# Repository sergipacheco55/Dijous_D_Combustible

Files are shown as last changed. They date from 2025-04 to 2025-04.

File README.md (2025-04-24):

View this project on [CADLAB.io](https://cadlab.io/project/29049). 

# EL COMBUSTIBLE

## Autors
- Raúl Carod (RaulCarod)
- Sergi Pacheco (sergipacheco55)

## Versió - v1.0 ## Curs - Assignatura de Disseny de PCBs amb KiCad - [Curs 2024-2025]

## Objectiu Descripció breu de l'objectiu del projecte.
L'objectiu del projecte és crear una pcb capaç de controlar el mecanisme de tancament de dipòsit del combustible d'un cotxe, controli el sensor de pressió de pneumàtics i el sensor digital de nivell de combustible i el funcionament de la bomba de combustible.
## Requisits i especificacions
- Una etapa regulador de tensió per alimentar tots el components de la placa.
- Tenir un microcontrolador encarregat del control de la nostra placa.
- Tenir una connexió BUS CAN, I2C.
- Una comuniació USART per connectar el microcontrolador a aparells extern ja ve sigui un ordinador.
- Tenir entrades com un boto per a que s'interección amb la placa.

## Diagrama de blocs
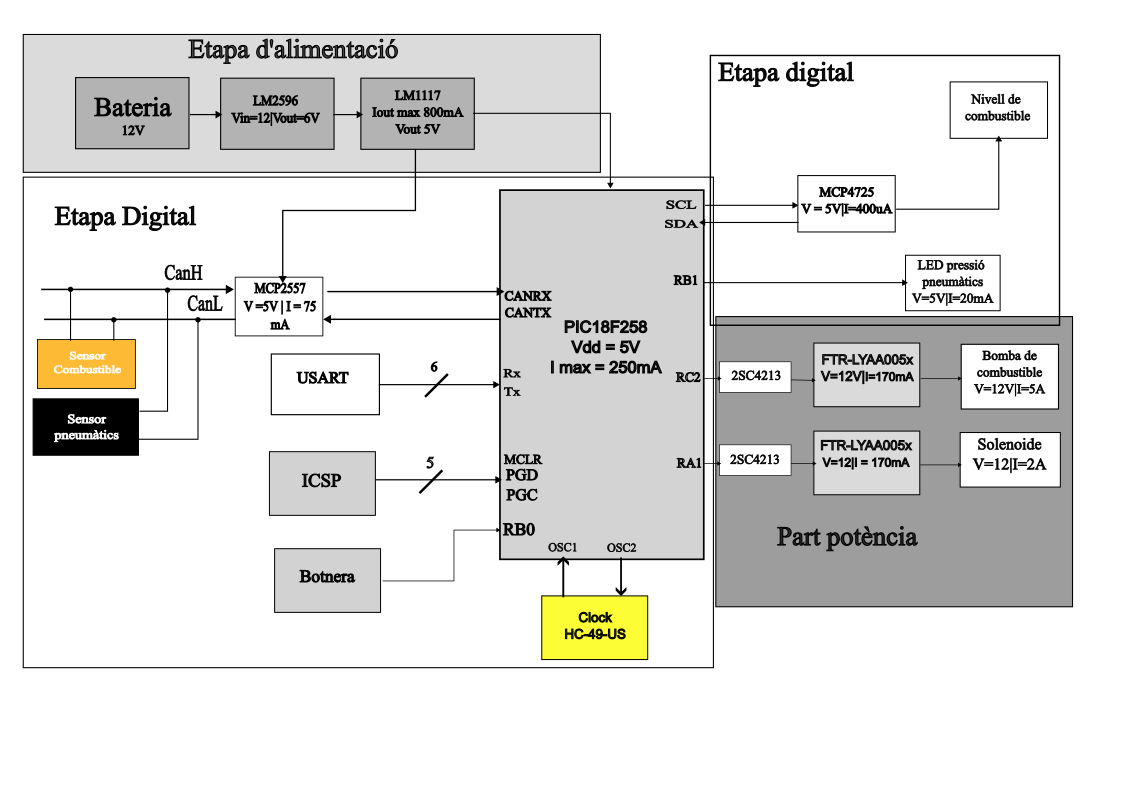
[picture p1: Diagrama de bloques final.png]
Diagrama de bloques


## Taula de components
| Descripció | Manufacturer Number | Package  | Datasheet | Proveïdor | Unitats |
|---|---|---|---|---|---|
| Regulador de tensió | LM1117 | SOT-223 | [Enllaç](https://www.ti.com/lit/ds/symlink/lm1117.pdf) | Mouser | 1 |
| Regulador de commutació | LM2596 | TO-220 / TO-263 | [Enllaç](https://www.ti.com/lit/ds/symlink/lm2596.pdf) |Mouser | 1 |
| Transceptor CAN | MCP2557 | SOIC-8  | [Enllaç](https://www.digikey.es/es/products/detail/microchip-technology/MCP2557FD-H-SN/6009299?productid=6009299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) | DigiKey | 1 |
| Microcontrolador | PIC18F258 | SOIC 28 | [Enllaç](https://ww1.microchip.com/downloads/en/devicedoc/39564c.pdf) | DigiKey / Mouser | 1 |
| Cristall de quars | abls-4.000mhz-b2-t | HC-49-SD | [Enllaç](https://www.mouser.es/ProductDetail/ABRACON/ABLS-4000MHZ-B2-T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) | Mouser | 1 |
| Convertidor DAC | MCP4725 | SOT-23-6 | [Enllaç](https://ww1.microchip.com/downloads/en/devicedoc/22039d.pdf) | DigiKey / Mouser | 1 |
| Transistor de control | 2SC4213 | SMD:SOT-323 | [Enllaç](https://toshiba.semicon-storage.com/info/docget.jsp?did=19305&prodName=2SC4213) | Mouser | 2 |
| Relé | Fujitsu_FTR-LYAA005Y | SPST-Vertical | [Enllaç](https://www.fujitsu.com/sg/imagesgig5/ftr-ly.pdf) | Mouse | 2 |
| Díode protector | PMEG6030EP | Diode_SMD:D_SOD-128 | [Enllaç](https://www.vishay.com/docs/88516/1n5400.pdf) | Mouser | 4 |
| Díode Zener | 1N5822 | DO-201AD | [Enllaç](http://www.vishay.com/docs/88526/1n5820.pdf) | Farnell España | 1 |
| LED Blau | 150080BS75000 | 0805_2012 | [Enllaç](https://www.we-online.com/components/products/datasheet/150080BS75000.pdf)| Digikey | 2 |
| LED Verd | 150080GS75000 | 0805_2012 | [Enllaç](https://www.we-online.com/components/products/datasheet/150080GS75000.pdf)| Digikey | 1 |
| LED Blau | 150080SS75000 | 0805_2012 | [Enllaç](https://www.we-online.com/components/products/datasheet/150080SS75000.pdf)| Digikey | 1 |
| Connector Bateria | 691137710002 | TERM BLK 2POS SIDE ENTRY 5MM PCB | [Enllaç](https://www.we-online.com/components/products/datasheet/691137710002.pdf) | Digikey | 1 |
| Connector 01x02 | 61300211121 | PinHeader_1x02_P2.54mm_Vertical | [Enllaç](https://www.we-online.com/components/products/datasheet/61300211121.pdf) |Digikey | 4 |
| Connector ISCP | 61200621621 | PinHeader_2x03_P2.54mm_Vertical | [Enllaç](https://www.we-online.com/components/products/datasheet/61200621621.pdf) | Digikey | 1 |
| Connector Usart | 61300611121 | PinHeader_1x06_P2.54mm_Vertical | [Enllaç](https://www.we-online.com/components/products/datasheet/61300611121.pdf) | Digikey | 1 |
| Connector 01x03 | G800LR305018EU | FanPinHeader_1x03_P2.54mm_Vertical | [Enllaç](https://cdn.amphenol-cs.com/media/wysiwyg/files/drawing/g800lrxxxxxxeu_1.pdf) |Mouser | 1 |
| Jumper | 60900213421 | JUMPER W/TEST PNT 1X2PINS 2.54MM | [Enllaç](https://www.we-online.com/components/products/datasheet/60900213421.pdf) | Digikey | 1 |
| Pulsador reset | SKRKAEE020 | SW_Push_SPST_NO_Alps_SKRK | [Enllaç](https://www.mouser.es/datasheet/2/15/SKRK-1370789.pdf) | Mouser | 1 |
| Connector DB9 | DE09-PT-1 | DSUB-9_Male_Vertical_P2.77x2.84mm | [Enllaç](https://app.adam-tech.com/products/download/data_sheet/198661/dxxx-pt-1-data-sheet.pdf) | Digikey | 1 |
| Díode de protecció de connexió | PMEG040V050EPD | CFP15_SOT-1289 | [Enllaç](https://assets.nexperia.com/documents/data-sheet/PMEG040V050EPD.pdf) | Digikey | 1 |

## Funcionalitats
- El mecanisme de tancament i obertura del dipòsit de combustible
- Un sensor digital del nivell de combustible
- El mecanisme que controli la bomba de combustible
- Un sensor que ens avisi quan la pressió dels pneumàtics sigui baixa

## Historial de canvis
| Data | Autor | Branch | Descripció |
|---|---|---|---|
| 2025-03-20 | Sergi Pacheco | `main` | Creació del projecte |
| 2025-03-24 | Raúl Carod| `main` | Diagrama de blocs |
| 2025-03-24 | Sergi Pacheco| `main`| Llista de materials|
| 2025-03-24 | Raúl Carod | `main`| Esquemàtic entrades |
| 2025-03-25 | Raúl Carod | `main`| Esquemàtic microcontrolador|
| 2025-03-26 | Sergi Pacheco| `main`| Últims Outputs|
| 2025-03-27 | Raúl Carod | `main`| Digrama de blocs+ Sortides esquematic actulaitzades |
| 2025-03-27 | Raúl Carod | `main`| Digrama de blocs correcció |
| 2025-03-31 | Sergi Pacheco | `main`| Correccions del esquemàtic |
| 2025-03-31 | Raúl Carod | `main`| Més correción al esquemàtic + actulització llista materials|
| 2025-04-01 | Raúl Carod | `main`| Correccions al esquemàtic + emprentas components |
| 2025-04-01 | Raúl Carod | `main` | Layout |
| 2025-04-01 | Sergi Pacheco | `main`| Seguiment amb el Layout |
| 2025-04-01 | Raúl Carod | `main`|Layout acabat |
| 2025-04-03 | Sergi Pacheco| `main`|  Canvis al esquemàtic, clock i iscp aprop micro|
| 2025-04-03 | Raúl Carod | `main`| Algunes correccions del layout |
| 2025-04-08 | Sergi Pacheco| `main`|  Augment tamany vies, amplada pistes i treure pads de ground a resistències|
| 2025-04-09 | Raúl Carod | `main`| Correcció d'errors en el layout |
| 2025-04-09 | Raúl Carod | `main`| Correccions del Layout i cambis en l'esquemàtic |
| 2025-04-19 | Raúl Carod | `main`| Layout final |
| 2025-04-19 | Raúl Carod | `main`| Correccionament de layout final |
| 2025-04-24 | Raúl Carod | `main`| Versió final del README |

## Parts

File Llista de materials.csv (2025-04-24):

Reference | Value | Datasheet | Footprint | Qty | DNP
C1,C9,C11 | 100nF | https://www.murata.com/en-us/api/pdfdownloadapi?cate=luCeramicCapacitorsSMD&partno=GRM31CD80J107MEA8%23 | Capacitor_SMD:C_1206_3216Metric | 3
C2 | 120uF | https://www.mouser.es/datasheet/2/447/KEM_A4001_EDK-3316599.pdf | Capacitor_SMD:CP_Elec_10x10 | 1
C3,C5 | 15p | https://www.mouser.es/datasheet/2/447/KEM_C1003_C0G_SMD-3316496.pdf | Capacitor_SMD:C_0805_2012Metric | 2
C4 | 100pF | https://www.mouser.es/datasheet/2/40/C0GNP0_KGM-3216332.pdf | Capacitor_SMD:C_1206_3216Metric | 1
C6 | 1nF | https://content.kemet.com/datasheets/KEM_C1007_X8R_ULTRA_150C_SMD.pdf | Capacitor_SMD:C_0603_1608Metric | 1
C7 | 220u | https://content.kemet.com/datasheets/KEM_A4001_EDK.pdf | Capacitor_SMD:CP_Elec_10x10 | 1
C8 | 10u | https://www.mouser.es/datasheet/2/447/KEM_T2005_T491-3316937.pdf | Capacitor_Tantalum_SMD:CP_EIA-3528-12_Kemet-T | 1
C10 | 22u | https://www.mouser.es/datasheet/2/447/KEM_T2005_T491-3316937.pdf | Capacitor_Tantalum_SMD:CP_EIA-3216-12_Kemet-S | 1
D1 | PMEG040V050EPD | https://assets.nexperia.com/documents/data-sheet/PMEG040V050EPD.pdf | Package_TO_SOT_SMD:Nexperia_CFP15_SOT-1289 | 1
D2 | 1N5822 | http://www.vishay.com/docs/88526/1n5820.pdf | Diode_THT:D_DO-201AD_P15.24mm_Horizontal | 1
D3 | LED_Power | https://www.we-online.com/components/products/datasheet/150080GS75000.pdf | LED_SMD:LED_0805_2012Metric | 1
D4 | LED | https://www.we-online.com/components/products/datasheet/150080SS75000.pdf | LED_SMD:LED_0805_2012Metric | 1
D5,D7 | LED_Relé | https://www.we-online.com/components/products/datasheet/150080BS75000.pdf | LED_SMD:LED_0805_2012Metric | 2
D6,D8,D9,D10 | PMEG6030EP | https://assets.nexperia.com/documents/data-sheet/PMEG6030EP.pdf | Diode_SMD:D_SOD-128 | 4
J1 | Screw_Terminal_01x02 | https://www.we-online.com/components/products/datasheet/691137710002.pdf | TerminalBlock:TerminalBlock_Altech_AK300-2_P5.00mm | 1
J2,J5,J6,J7 | Conn_01x02 | https://www.we-online.com/components/products/datasheet/61300211121.pdf | Connector_PinHeader_2.54mm:PinHeader_1x02_P2.54mm_Vertical | 4
J3 | Conn_02x03_Counter_Clockwise | https://www.we-online.com/components/products/datasheet/61200621621.pdf | Connector_PinHeader_2.54mm:PinHeader_2x03_P2.54mm_Vertical | 1
J4 | DE9_Plug | https://app.adam-tech.com/products/download/data_sheet/198661/dxxx-pt-1-data-sheet.pdf | Connector_Dsub:DSUB-9_Male_Vertical_P2.77x2.84mm | 1
J8 | Conn_01x06 | https://www.we-online.com/components/products/datasheet/61300611121.pdf | Connector_PinHeader_2.54mm:PinHeader_1x06_P2.54mm_Vertical | 1
JP1 | Jumper_3_Open | https://cdn.amphenol-cs.com/media/wysiwyg/files/drawing/g800lrxxxxxxeu_1.pdf | Connector:FanPinHeader_1x03_P2.54mm_Vertical | 1
K1,K2 | Fujitsu_FTR-LYAA005x | https://www.fujitsu.com/sg/imagesgig5/ftr-ly.pdf | Relay_THT:Relay_SPST-NO_Fujitsu_FTR-LYAA005x_FormA_Vertical | 2
L1 | 68u | https://www.mouser.es/datasheet/2/3/AIML_1206-3318159.pdf | Inductor_SMD:L_1206_3216Metric | 1
Q1,Q2 | 2SC4213 | https://toshiba.semicon-storage.com/info/docget.jsp?did=19305&prodName=2SC4213 | Package_TO_SOT_SMD:SOT-323_SC-70 | 2
R1 | 15k | ~ | Resistor_SMD:R_1206_3216Metric | 1
R2,R3 | 60 | ~ | Resistor_SMD:R_1206_3216Metric | 2
R4 | 0 | ~ | Resistor_SMD:R_1206_3216Metric | 1 | x
R5,R15,R18 | 1k | ~ | Resistor_SMD:R_1206_3216Metric | 3
R6 | 4,7K | ~ | Resistor_SMD:R_1206_3216Metric | 1
R7,R8,R14 | 4,7k | ~ | Resistor_SMD:R_1206_3216Metric | 3
R9,R10 | 10K | ~ | Resistor_SMD:R_1206_3216Metric | 2
R11 | 330 | ~ | Resistor_SMD:R_1206_3216Metric | 1
R12 | 515 | ~ | Resistor_SMD:R_1206_3216Metric | 1
R13,R16 | 290 | ~ | Resistor_SMD:R_1206_3216Metric | 2
R17 | 4.7K | ~ | Resistor_SMD:R_1206_3216Metric | 1
R19 | 10k | ~ | Resistor_SMD:R_0805_2012Metric | 1
SW1 | SW_Push | https://www.mouser.es/datasheet/2/15/SKRK-1370789.pdf | Button_Switch_SMD:SW_Push_SPST_NO_Alps_SKRK | 1
U1 | MCP2557FD-xSN | https://ww1.microchip.com/downloads/en/DeviceDoc/20005533A.pdf | Package_SO:SOIC-8_3.9x4.9mm_P1.27mm | 1
U2 | LM2596S-ADJ | http://www.ti.com/lit/ds/symlink/lm2596.pdf | Library:TO-263-5_TabPin3 | 1
U3 | PIC18F258-I/SO | PIC18F258-I/SO | Librery_SOIC28:SOIC28-W_MC_MCH | 1
U4 | LM1117DT-5.0 | http://www.ti.com/lit/ds/symlink/lm1117.pdf | Library:TO-252-3_TabPin2 | 1
U5 | MCP4725xxx-xCH | http://ww1.microchip.com/downloads/en/DeviceDoc/22039d.pdf | Package_TO_SOT_SMD:SOT-23-6 | 1
Y1 | HC-49-US | https://www.mouser.es/datasheet/2/3/abls-1664338.pdf | Crystal:Crystal_SMD_HC49-SD | 1

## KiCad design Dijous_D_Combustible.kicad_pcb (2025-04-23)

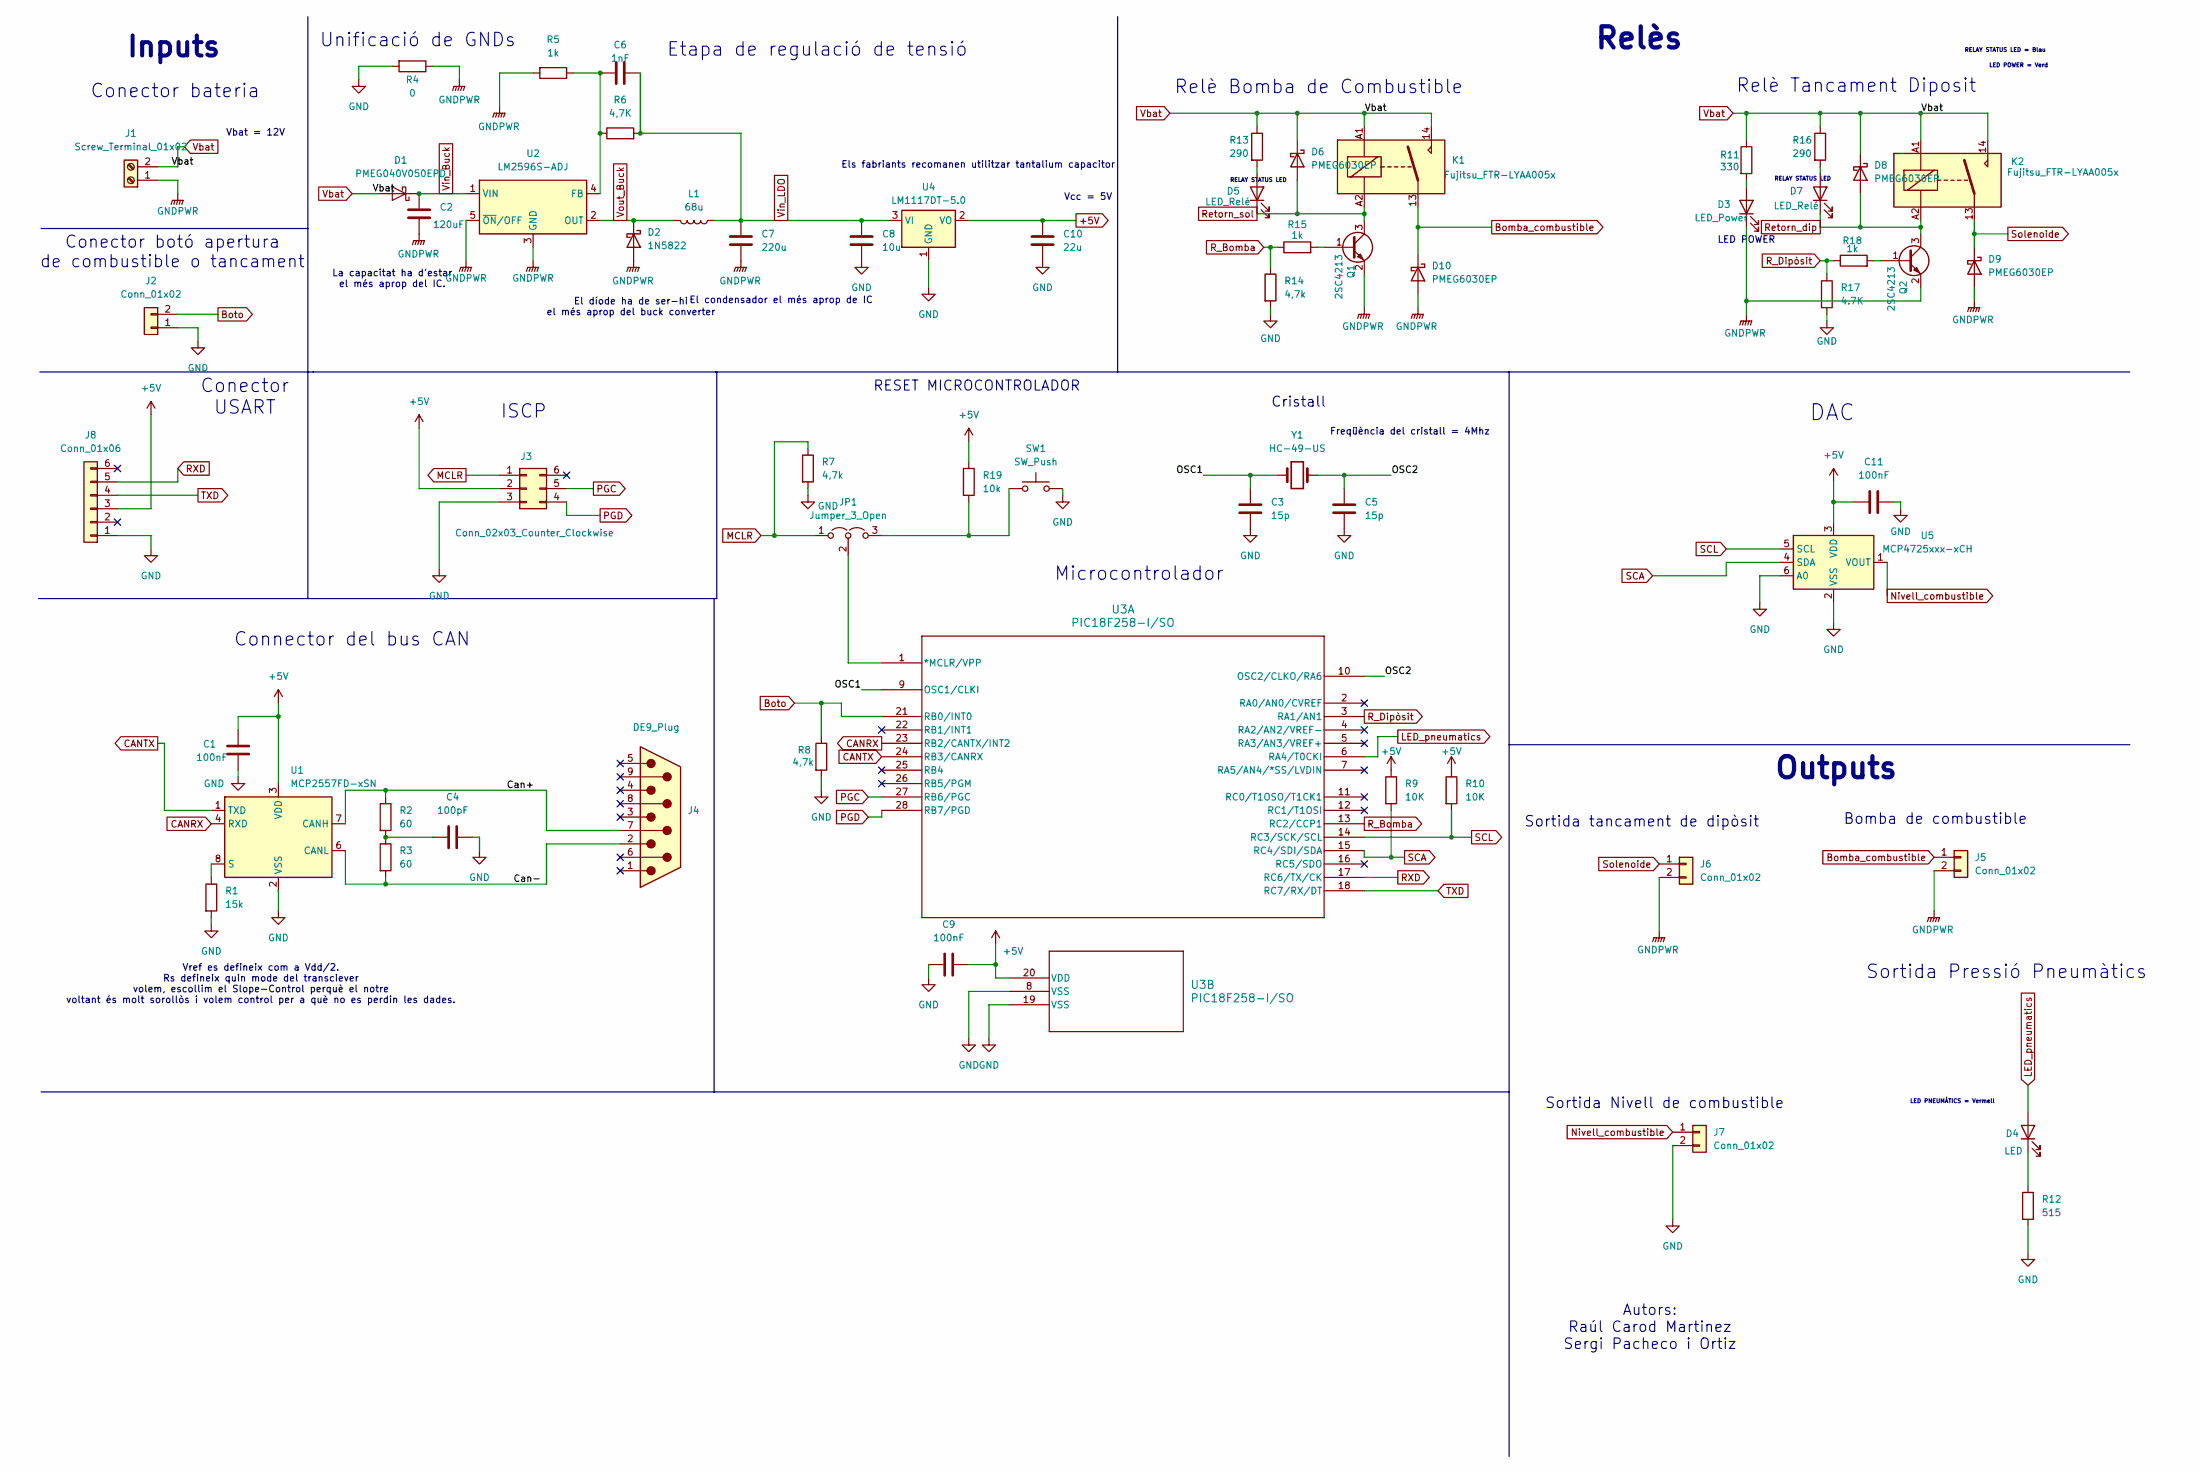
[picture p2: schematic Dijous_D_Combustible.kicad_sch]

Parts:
C1, C9, C11: 100nF; C_1206_3216Metric
C2: 120uF; CP_Elec_10x10
C3, C5: 15p; C_0805_2012Metric
C4: 100pF; C_1206_3216Metric
C6: 1nF; C_0603_1608Metric
C7: 220u; CP_Elec_10x10
C8: 10u; CP_EIA-3528-12_Kemet-T
C10: 22u; CP_EIA-3216-12_Kemet-S
D1: PMEG040V050EPD; Nexperia_CFP15_SOT-1289
D2: 1N5822; D_DO-201AD_P15.24mm_Horizontal
D3: LED_Power; LED_0805_2012Metric
D4: LED; LED_0805_2012Metric
D5, D7: LED_Relé; LED_0805_2012Metric
D6, D8, D9, D10: PMEG6030EP; D_SOD-128
J1: Screw_Terminal_01x02; TerminalBlock_Altech_AK300-2_P5.00mm
J2, J5, J6, J7: Conn_01x02; PinHeader_1x02_P2.54mm_Vertical
J3: Conn_02x03_Counter_Clockwise; PinHeader_2x03_P2.54mm_Vertical
J4: DE9_Plug; DSUB-9_Male_Vertical_P2.77x2.84mm
J8: Conn_01x06; PinHeader_1x06_P2.54mm_Vertical
JP1: Jumper_3_Open; FanPinHeader_1x03_P2.54mm_Vertical
K1, K2: Fujitsu_FTR-LYAA005x; Relay_SPST-NO_Fujitsu_FTR-LYAA005x_FormA_Vertical
L1: 68u; L_1206_3216Metric
Q1, Q2: 2SC4213; SOT-323_SC-70
R1: 15k; R_1206_3216Metric
R2, R3: 60; R_1206_3216Metric
R4: 0; R_1206_3216Metric
R5, R15, R18: 1k; R_1206_3216Metric
R6: 4,7K; R_1206_3216Metric
R7, R8, R14: 4,7k; R_1206_3216Metric
R9, R10: 10K; R_1206_3216Metric
R11: 330; R_1206_3216Metric
R12: 515; R_1206_3216Metric
R13, R16: 290; R_1206_3216Metric
R17: 4.7K; R_1206_3216Metric
R19: 10k; R_0805_2012Metric
SW1: SW_Push; SW_Push_SPST_NO_Alps_SKRK
U1: MCP2557FD-xSN; SOIC-8_3.9x4.9mm_P1.27mm
U2: LM2596S-ADJ; TO-263-5_TabPin3
U3: PIC18F258-I/SO; SOIC28-W_MC_MCH
U4: LM1117DT-5.0; TO-252-3_TabPin2
U5: MCP4725xxx-xCH; SOT-23-6
Y1: HC-49-US; Crystal_SMD_HC49-SD

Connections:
+5V: C1.1, C9.2, C10.1, C11.1, J3.2, J8.3, R9.1, R10.1, R19.1, U1.3 (VDD), U3.20 (VDD), U4.2 (VO), U5.3 (VDD)
/Can+: J4.7, R2.1, U1.7 (CANH)
/Can-: J4.2, R3.2, U1.6 (CANL)
/OSC1: C3.1, U3.9 (OSC1/CLKI), Y1.1
/OSC2: C5.2, U3.10 (OSC2/CLKO/RA6), Y1.2
Bomba_combustible: D10.1 (K), J5.1, K1.13
Boto: J2.2, R8.1, U3.21 (RB0/INT0)
CANRX: U1.4 (RXD), U3.23 (RB2/CANTX/INT2)
CANTX: U1.1 (TXD), U3.24 (RB3/CANRX)
GND: C1.2, C3.2, C4.2, C5.1, C8.2, C9.1, C10.2, C11.2, J2.1, J3.3, J7.2, J8.1, R1.2, R4.2, R7.2, R8.2, R12.2, R14.2, R17.2, SW1.2, U1.2 (VSS), U3.8 (VSS), U3.19 (VSS), U4.1 (GND), U5.2 (VSS), U5.6 (A0)
GNDPWR: C2.2, C7.2, D2.2 (A), D3.1 (K), D9.2 (A), D10.2 (A), J1.1, J5.2, J6.2, Q1.2 (E), Q2.2 (E), R4.1, R5.2, U2.3 (GND), U2.5 (~ON/OFF)
LED_pneumatics: D4.2 (A), U3.6 (RA4/T0CKI)
MCLR: J3.1, JP1.1 (A), R7.1
unnamed: C4.1, R2.2, R3.1
unnamed: D3.2 (A), R11.2
unnamed: D4.1 (K), R12.1
unnamed: D5.2 (A), R13.2
unnamed: D7.2 (A), R16.2
unnamed: JP1.3 (B), R19.2, SW1.1
unnamed: JP1.2 (C), U3.1 (*MCLR/VPP)
unnamed: Q1.1 (B), R15.2
unnamed: Q2.1 (B), R18.2
unnamed: R1.1, U1.8 (S)
unnamed: C6.1, R5.1, R6.1, U2.4 (FB)
Nivell_combustible: J7.1, U5.1 (VOUT)
PGC: J3.5, U3.27 (RB6/PGC)
PGD: J3.4, U3.28 (RB7/PGD)
RXD: J8.5, U3.17 (RC6/TX/CK)
R_Bomba: R14.1, R15.1, U3.13 (RC2/CCP1)
R_Dipòsit: R17.1, R18.1, U3.3 (RA1/AN1)
Retorn_dip: D7.1 (K), D8.2 (A), K2.A2, Q2.3 (C)
Retorn_sol: D5.1 (K), D6.2 (A), K1.A2, Q1.3 (C)
SCA: R9.2, U3.15 (RC4/SDI/SDA), U5.4 (SDA)
SCL: R10.2, U3.14 (RC3/SCK/SCL), U5.5 (SCL)
Solenoide: D9.1 (K), J6.1, K2.13
TXD: J8.4, U3.18 (RC7/RX/DT)
Vbat: D1.1 (A), D1.2 (A), D6.1 (K), D8.1 (K), J1.2, K1.14, K1.A1, K2.14, K2.A1, R11.1, R13.1, R16.1
Vin_Buck: C2.1, D1.3 (K), U2.1 (VIN)
Vin_LDO: C6.2, C7.1, C8.1, L1.1, R6.2, U4.3 (VI)
Vout_Buck: D2.1 (K), L1.2, U2.2 (OUT)

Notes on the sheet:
DAC
Relè Bomba de Combustible
Cristall
LED POWER = Verd
RESET MICROCONTROLADOR
El díode ha de ser-hi el més aprop del buck converter
Etapa de regulació de tensió
RELAY STATUS LED = Blau
Outputs
Conector USART
El condensador el més aprop de IC
RELAY STATUS LED
Vref es defineix com a Vdd/2. Rs defineix quin mode del transciever volem, escollim el Slope-Control perquè el notre voltant és molt sorollòs i volem control per a què no es perdin les dades.
LED PNEUMÀTICS = Vermell
Vbat = 12V
Sortida tancament de dipòsit
Vcc = 5V
Bomba de combustible
Unificació de GNDs
Freqüència del cristall = 4Mhz
Inputs
Relès
Sortida Pressió Pneumàtics
Sortida Nivell de combustible
Microcontrolador
Els fabriants recomanen utilitzar tantalium capacitor
LED POWER
La capacitat ha d'estar el més aprop del IC.
Autors: Raúl Carod Martinez Sergi Pacheco i Ortiz
Conector botó apertura de combustible o tancament
Conector bateria
Relè Tancament Diposit
Connector del bus CAN
ISCP

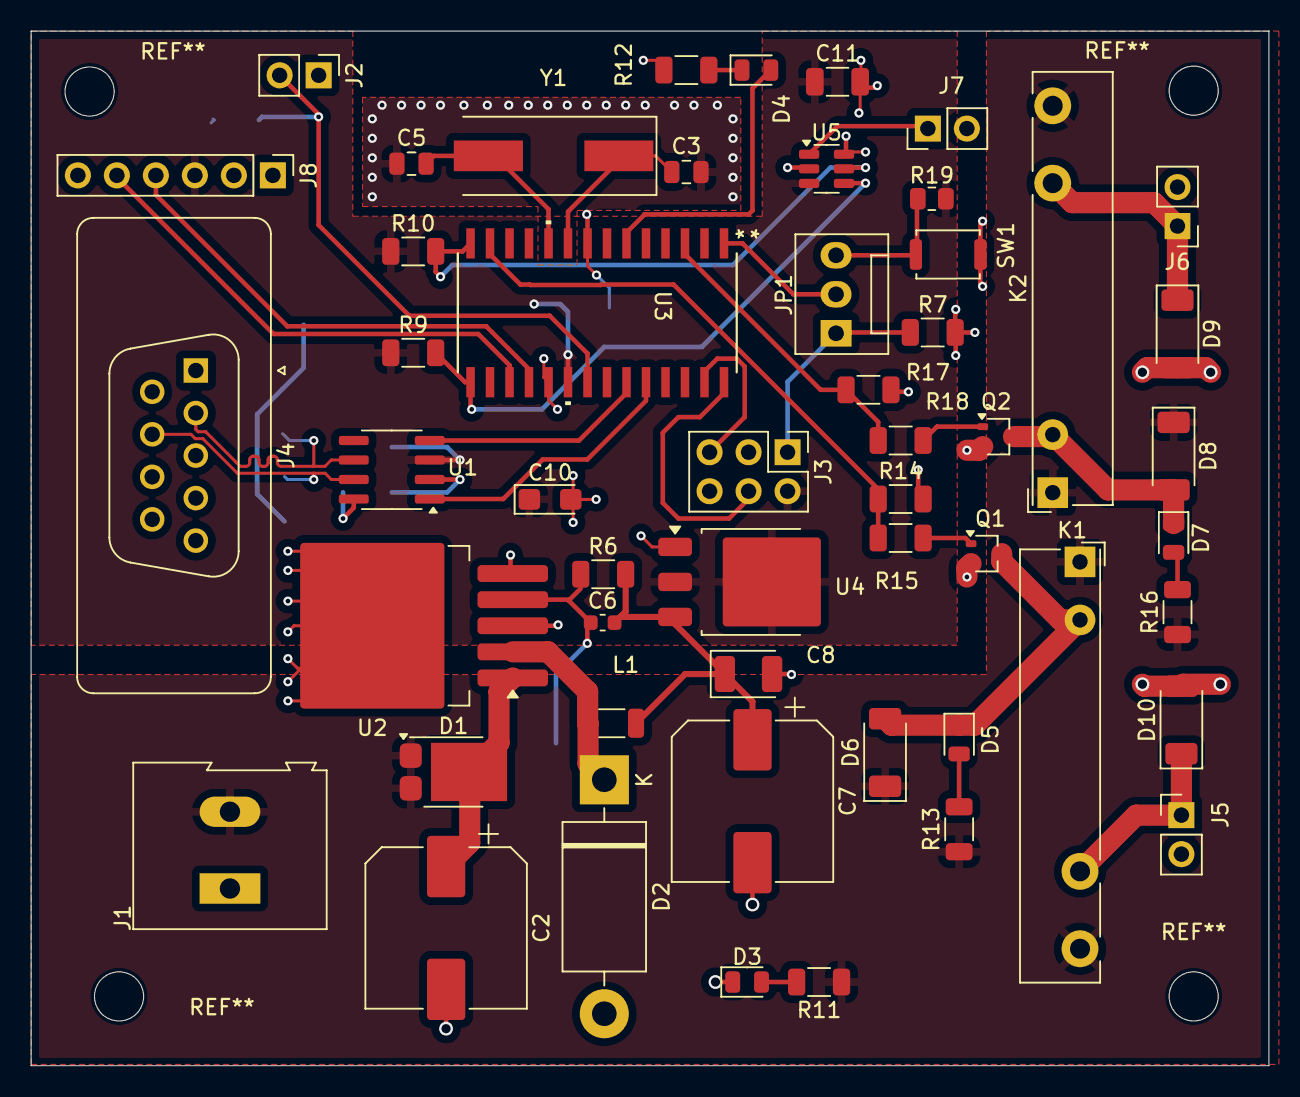
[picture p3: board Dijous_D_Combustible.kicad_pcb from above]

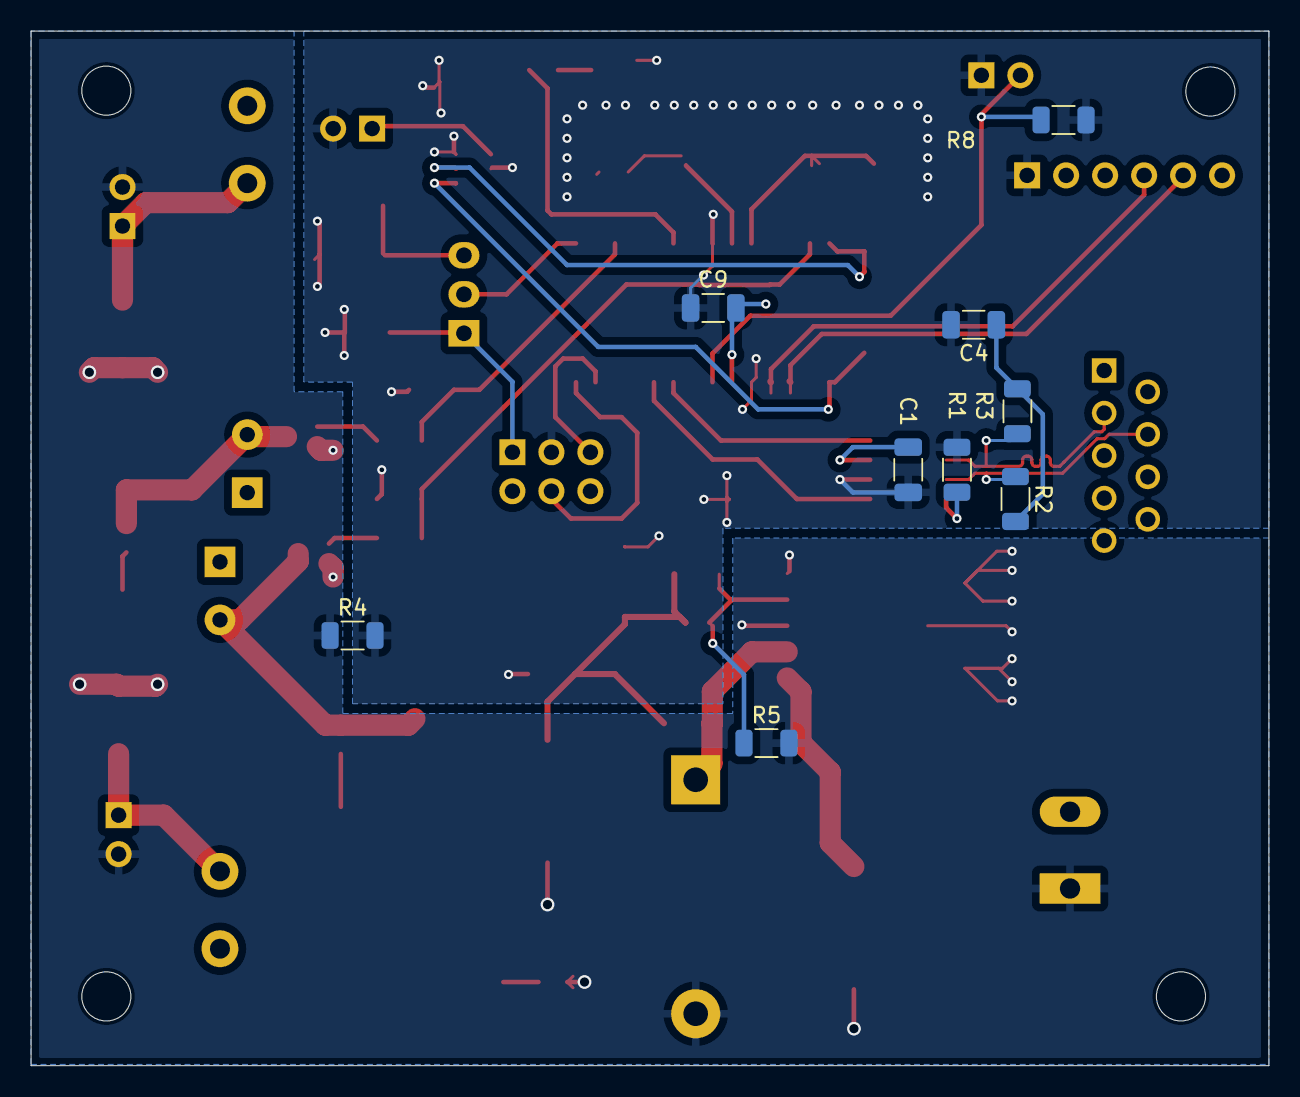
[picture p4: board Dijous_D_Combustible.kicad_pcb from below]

Board: 2 copper layers, 80.6 x 67.4 mm, 61 parts (9 on the bottom side), 40 nets.

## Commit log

2025-03-24 Update README.md
    He afegit components a la taula de components
2025-03-24 Rename Diagrama de bloques.png to Diagrama%20de%20bloques%20final.png
2025-03-24 Delete Diagrama%20de%20bloques%20final.png
    He eliminat el diagrama de blocs
2025-03-24 Rename Diagrama.png to Diagrama de bloques final.png
2025-03-24 Historial de canvis
2025-03-26 Add files via upload
    He afegit els outputs que quedaven
    [Dijous_D_Combustible (1).kicad_sch]
2025-03-27 Cambio de nombres
    [Dijous_D_Combustible (1).kicad_sch, Dijous_D_Combustible.kicad_sch]
2025-03-27 Ultim canvi esquemàtic
    [Dijous_D_Combustible.kicad_sch]
2025-03-27 Diagrama de blocs actualitzat i esquema
    [Dijous_D_Combustible.kicad_sch]
2025-03-31 Create Dijous_D_Combustible (amb correccions).kicad_sch
    [Dijous_D_Combustible (amb correccions).kicad_sch]
2025-03-31 README i kicad.sch
    [Dijous_D_Combustible (amb correccions).kicad_sch]
2025-04-01 Readme & Esquemàtic
    [Dijous_D_Combustible (amb correccions).kicad_sch, Dijous_D_Combustible.kicad_sch]
2025-04-02 README & Layout
    [Dijous_D_Combustible.kicad_pcb, Dijous_D_Combustible.kicad_sch]
2025-04-03 canvis esquemàtic, cristall i iscp aprop micro
    [Dijous_D_Combustible.kicad_sch]
2025-04-03 canvis esquemàtic
    [Dijous_D_Combustible.kicad_sch]
2025-04-03 Layout & README
    [Dijous_D_Combustible.kicad_pcb]
2025-04-08 Augment tamany vies i amplada pistes
    [Dijous_D_Combustible.kicad_pcb]
2025-04-08 fora grounds de resistències
    [Dijous_D_Combustible.kicad_pcb]
2025-04-09 README & LAYOUT & Esquematic
    [Dijous_D_Combustible.kicad_pcb, Dijous_D_Combustible.kicad_sch]
2025-04-10 Hola caracola
    [Dijous_D_Combustible.kicad_pcb, Dijous_D_Combustible.kicad_sch]
2025-04-22 Can transciever
    [Dijous_D_Combustible.kicad_pcb, Dijous_D_Combustible.kicad_sch, Llista de materials.csv]
2025-04-22 Cambio en los auxiliares por el transciever
    [Llista de materials.csv]
2025-04-23 De todo
    [Dijous_D_Combustible-B_Cu.gbr, Dijous_D_Combustible-B_Mask.gbr, Dijous_D_Combustible-B_Paste.gbr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]
2025-04-23 No se
    [Llista de materials.csv]
2025-04-24 De tot
    [Llista de materials.csv]
